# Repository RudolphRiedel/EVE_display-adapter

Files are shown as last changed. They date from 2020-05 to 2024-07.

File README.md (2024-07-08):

# EVE_display-adapter for 3D printers

These adapter boards connect a couple of FTDI/Bridgetek based FT81x/BT81x display modules with 3D-printer controller boards.
Basic support is present already in Marlin Bugfix 2.0x: ExtUI
Recommended are 4.3" displays with 480x272 or 5.0" displays with 800x480.

The form factor with the two mounting holes allows replacing a RepRap gfx-display.

L-D5019-01-0x: to be used with displays from Matrix Orbital or Riverdi.

L-D5019-05-0x: to be used with displays from Crystalfontz.

The design source files are for Altium Designer.

But everything else to order boards and build them without AD is included as well.

The design of the "EXP1" header is optimised for the Fysetc Cheetah as I do have two of these and can therefore
test my changes in Marlin with my displays.

Also, the Cheetah is one of the very few 3D-printer controller boards that allows to use hardware-SPI with the display.

The adapter boards can also be configured to be used with at least the original CR-10/Ender-3 boards using software-SPI.

Recommended displays for now with L-D5019-01-0x:
- EVE3-43G https://www.matrixorbital.com/eve3-43g
- EVE3-50G https://www.matrixorbital.com/eve3-50g
- RVT43ULBNWC00 (RiTFT-43-CAP-UX) https://riverdi.com/product/ritft43capux/

Recommended displays for now with L-D5019-05-0x:
- CFAF800480E0-050SC https://www.crystalfontz.com/product/cfaf800480e1050sca11-800x480-eve-accelerated-tft

Before connecting any display to your controller board, make sure the board can take the additional load on the 5V!

And you need to use a flat-flex-cable with connections on opposite sides.

The D5019-01-04 and D5019-05-02 boards do work both, I was not satisfied with the loudness of the speaker though.

I ran a series of performance tests with two microcontroller boards and the same 5cm cable from these boards to the display-adapter boards.

One of the microcontroller boards was this: https://github.com/RudolphRiedel/SAMC21_one
The "SAMC21 One" has an ATSAMC21E18A running at 48MHz and 5.0V.

The other one has an ATSAME51J19A running at 120MHz and 3.3V.

The D5019-01-04 was tested with an EVE3-50G featuring a BT815 running at 72MHz.

The D5019-05-02 was tested with a CFAF800480E0-050SC featuring a FT813 running at 60MHz.

Both boards performed similar enough to present the numbers together.

ATSAMC21
- 12MHz max for reliable touch events
- 35MHz max for still displaying a stable image

ATSAME51
- 17MHz max for reliable touch events
- 40MHz max for still displaying a stable image

Note, I reduced the main clock to find the maximum read spead and overclocked the controllers for the maximum write speed.
Also the maximum write speed is out of spec for both the FT813 and the BT815.

As the target speed for these boards with Marlin is 8MHz on hardware-SPI and <2MHz on software-spi,
I conclude that the performance of the SPI on these boards is well within the desired limits.

D5019-01-05 with the 3.3V LDO works fine with a EVE3-43G that has been modified to dual supply.

D5019-05-03 is ordered, it has the same 3.3V LDO and speaker as the D5019-01-05.

# EVE_display-adapter for use with breadboards

L-D5019-08-0x: simplified PCB to be used with displays from Matrix Orbital or Riverdi.

The schematic is pretty much the same as L-D5019-01 with a few modifications.
- all the series resistors are set to 56R
- the SPI line filter capacitors are set to not populated
- the "amplifier" circuit and the speaker is gone
- the 2x5 header for 3D printers is replaced with a 1x7 header
- an additional 1x8 header allows to connect a logic-analyzer plus an extra GND pin for split-supply setups
- the layout and the pinout of the 1x7 header is optimized for the pinout of the 20 pin ffc
- there is a little more space around the parts to allow for easier soldering
- pinout printed in copper on the pcb with no solder mask, no more need to check the documentation when connecting the board with jumper wires

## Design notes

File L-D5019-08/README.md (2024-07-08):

# EVE_display-adapter for use with evaluation boards

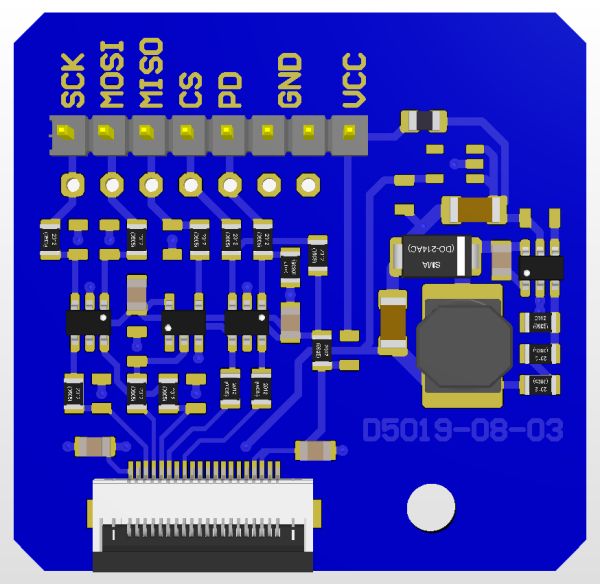
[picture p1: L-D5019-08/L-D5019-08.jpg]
L-D5019-08


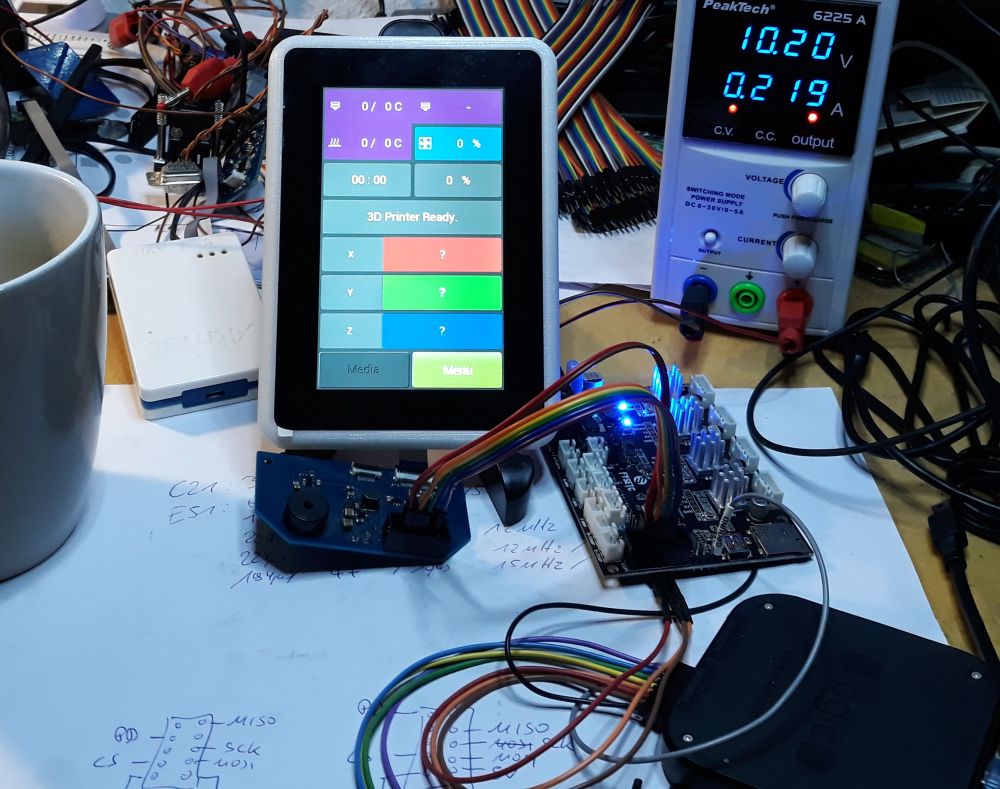
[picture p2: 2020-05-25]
Images/Marlin_Cheetah_EVE3-50G.jpg

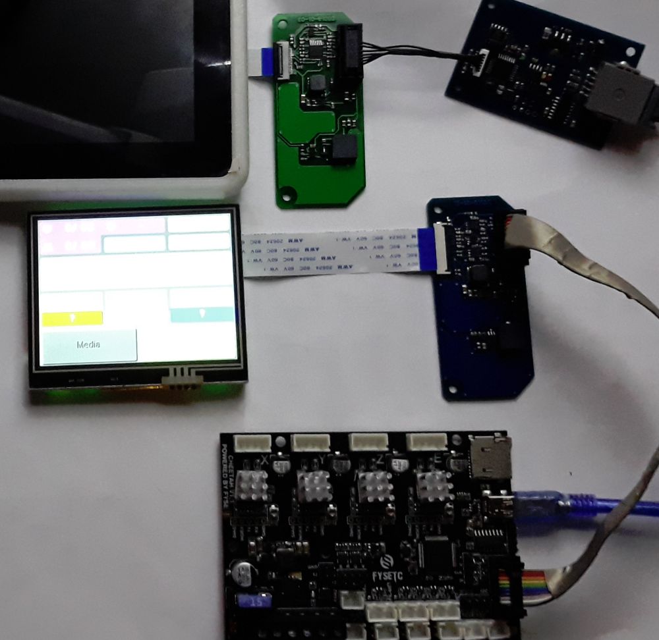
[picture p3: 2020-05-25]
Images/Marlin_Cheetah_Crystalfontz.jpg

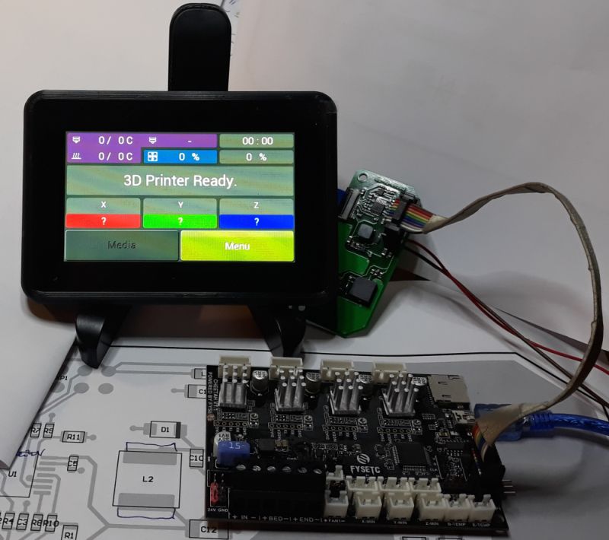
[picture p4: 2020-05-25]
Images/Marlin_Cheetah_EVE3-43G.jpg

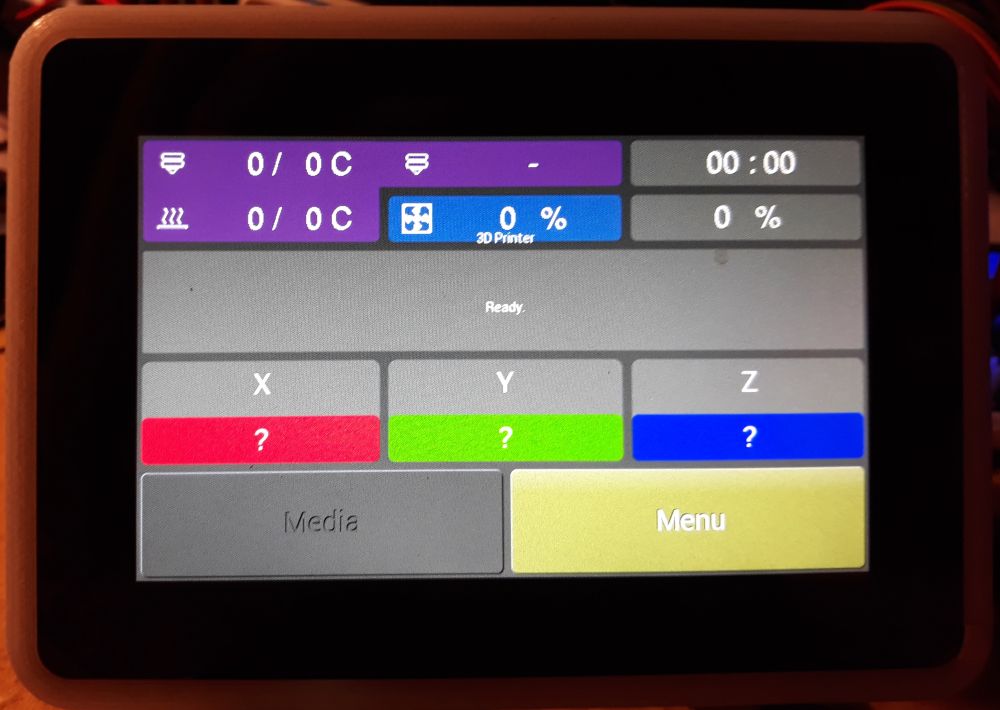
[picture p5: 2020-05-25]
Images/Marlin_EVE3-50G.jpg

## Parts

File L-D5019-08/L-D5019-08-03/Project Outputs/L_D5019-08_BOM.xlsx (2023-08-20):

Comment | Designator | Footprint | JLCPCB Part #
100n | C100, C106, C110 | 0805 | C49678
4µ7 | C101, C107 | 0805 | C1779
4µ7 | C111 | 1206 | C29823
22µF | C112 | 1206 | C12891
MBRA340T3G‎ | D100 | SMA | C8678
0R0 | L100, R102 | 0805 | C17477
xNR6028T4R7M | L101 | 6x6 mm | do not populate
56R | R100, R101, R103, R104, R107, R108, R109, R110, R112, R113 | 0805 | C17757
10k | R106, R111, R116, R117 | 0805 | C17414
22k | R115 | 0805 | C17560
x74LVC2G17 | U100, U101 | SOT23-6 | C3294723
x74VHC1GT125 | U102 | SOT23-5 | C457671
RT8259GE | U103 | SOT23-6 | C16819
x1x8 2,54mm | X100 |  | do not populate
687120149022 | X101 | FPC 0.5mm | C262274

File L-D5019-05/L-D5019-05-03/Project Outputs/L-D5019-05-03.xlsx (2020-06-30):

Quantity | Designator | Value | PackageDescription | Description | Manufacturer | Part Number | Distributor_1 | Distributor_1_Part_Number
4 | C1, C6, C9, C11 | 100n | 0805 | 0805 Chip Capacitor |  | CAPC_0805
4 | C2, C3, C4, C5 | 22p | 0805 | 0805 Chip Capacitor |  | CAPC_0805
4 | C7, C14, C16, C18 | 4µ7 | 0805 | 0805 Chip Capacitor |  | CAPC_0805
1 | D3 | TS4148 RY | 0805 | Small Signal Diode IF 0.3A, VR 75V, 0805 | TSC | TSC_TS4148 RY
1 | EXP1 | 2x5 2,54mm |  | Pin-Header 2,54 mm 2x5pins, shrouded |  | PINH_2x5_2_54
1 | H1 | CT-1205H-SMT | SMT, 13x13 | Speaker, Magnetic, 47R, 60mA, 88dBA, SMT, 12.8 x 12.8 mm, height 10 mm | CUI | CT-1205H-SMT | Digi-Key | 102-1266-1-ND
1 | L1 | 0R0 | 0805 | 0805 Chip Inductor |  | INDC_0805
4 | R2, R15, R18, R24 | 0R0 | 0805 | 0805 Chip Resistor |  | RESC_0805
10 | R3, R4, R5, R6, R8, R9, R10, R11, R14, R16 | 10R | 0805 | 0805 Chip Resistor |  | RESC_0805
2 | R7, R12 | 10k | 0805 | 0805 Chip Resistor |  | RESC_0805
1 | R19 | 1k | 0805 | 0805 Chip Resistor |  | RESC_0805
2 | U1, U2 | 74LVC2G17 | SOT23-6 | Dual Schmitt-Trigger Buffer with 5.5V tolerant inputs | TI | 74LVC2G17 | Digi-Key | 296-SN74LVC2G17DBVRCT-ND‎
2 | U3, U4 | 74VHC1GT125 | SOT23-5 | 1x Buffer with OE; 3-state,Level Shifter 3,3V to 5V and 5V to 3.3V | ON Semiconductor | 74VHC1GT125 | Farnell | 1703291
1 | U6 | MIC5504-3.3YM5 | SOT23-5 | 300 mA LDO, Vin=2,5V…5,5V, Vout= 3,3V, -40°C..125°C | Microchip | MIC5504-3.3YM5 | Farnell | 2510377
1 | V1 | BC817 | SOT23 | NPN Transistor SOT23, 1=B, 2=C, 3=E |  | BC817
1 | X1 | WE_687130149022 | FPC 0.5mm | 30pin WR-FPC 0.50 mm SMT ZIF Horizontal - Bottom Contact | Wuerth | WE_687130149022 | Digi-Key | 732-6007-1-ND

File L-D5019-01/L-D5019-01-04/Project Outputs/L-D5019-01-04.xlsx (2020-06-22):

Quantity | Designator | Value | PackageDescription | Description | Manufacturer | Part Number | Distributor_1 | Distributor_1_Part_Number
5 | C1, C6, C9, C11, C13 | 100n | 0805 | 0805 Chip Capacitor |  | CAPC_0805
4 | C2, C3, C4, C5 | 22p | 0805 | 0805 Chip Capacitor |  | CAPC_0805
2 | C7, C14 | 4µ7 | 0805 | 0805 Chip Capacitor |  | CAPC_0805
1 | C15 | 22µF | 1206 | 1206 Chip Capacitor |  | CAPC_1206
1 | D1 | TS4148 RY | 0805 | Small Signal Diode IF 0.3A, VR 75V, 0805 | TSC | TSC_TS4148 RY
1 | D2 | ES07D | DO-219AB | Ultrafast Rectifier Surface Mount, IF 0.5A, VR 100V, DO-219AB, AEC-Q101 | Vishay | ES07D
1 | EXP1 | 2x5 2,54mm |  | Pin-Header 2,54 mm 2x5pins, shrouded |  | PINH_2x5_2_54
1 | H1 | PKM17EPP-2002-B0 | THT, 17mm dia | Speaker, Piezo, THT, dia 17mm, height 8.6 mm | Murata | PKM17EPP-2002-B0 | Digi-Key | 490-4688-ND
1 | L1 | 0R0 | 0805 | 0805 Chip Inductor |  | INDC_0805
1 | L2 | VLS6045AF-4R7M | 6x6 mm | 4,7µH, shielded, 4,7A, 26mR | TDK | VLS6045AF-4R7M | Digi-Key | 445-180835-1-ND
3 | R2, R15, R18 | 0R0 | 0805 | 0805 Chip Resistor |  | RESC_0805
10 | R3, R4, R5, R6, R8, R9, R10, R11, R14, R16 | 10R | 0805 | 0805 Chip Resistor |  | RESC_0805
5 | R7, R12, R20, R22, R23 | 10k | 0805 | 0805 Chip Resistor |  | RESC_0805
2 | R17, R19 | 1k | 0805 | 0805 Chip Resistor |  | RESC_0805
1 | R21 | 22k | 0805 | 0805 Chip Resistor |  | RESC_0805
2 | U1, U2 | 74LVC2G17 | SOT23-6 | Dual Schmitt-Trigger Buffer with 5.5V tolerant inputs | TI | 74LVC2G17 | Digi-Key | 296-SN74LVC2G17DBVRCT-ND‎
2 | U3, U4 | 74VHC1GT125 | SOT23-5 | 1x Buffer with OE; 3-state,Level Shifter 3,3V to 5V and 5V to 3.3V | ON Semiconductor | 74VHC1GT125 | Farnell | 1703291
1 | U5 | RT8259GE | SOT23-6 | Step-Down DC/DC Regulator, 24V, 1.2A, 1,4MHz | Richtek | RT8259GE | Digi-Key | 1028-1497-1-ND
1 | V1 | BC817 | SOT23 | NPN Transistor SOT23, 1=B, 2=C, 3=E |  | BC817
1 | X1 | WE_687120149022 | FPC 0.5mm | 20pin WR-FPC 0.50 mm SMT ZIF Horizontal - Bottom Contact | Wuerth | WE_687120149022 | Digi-Key | 732-6002-1-ND

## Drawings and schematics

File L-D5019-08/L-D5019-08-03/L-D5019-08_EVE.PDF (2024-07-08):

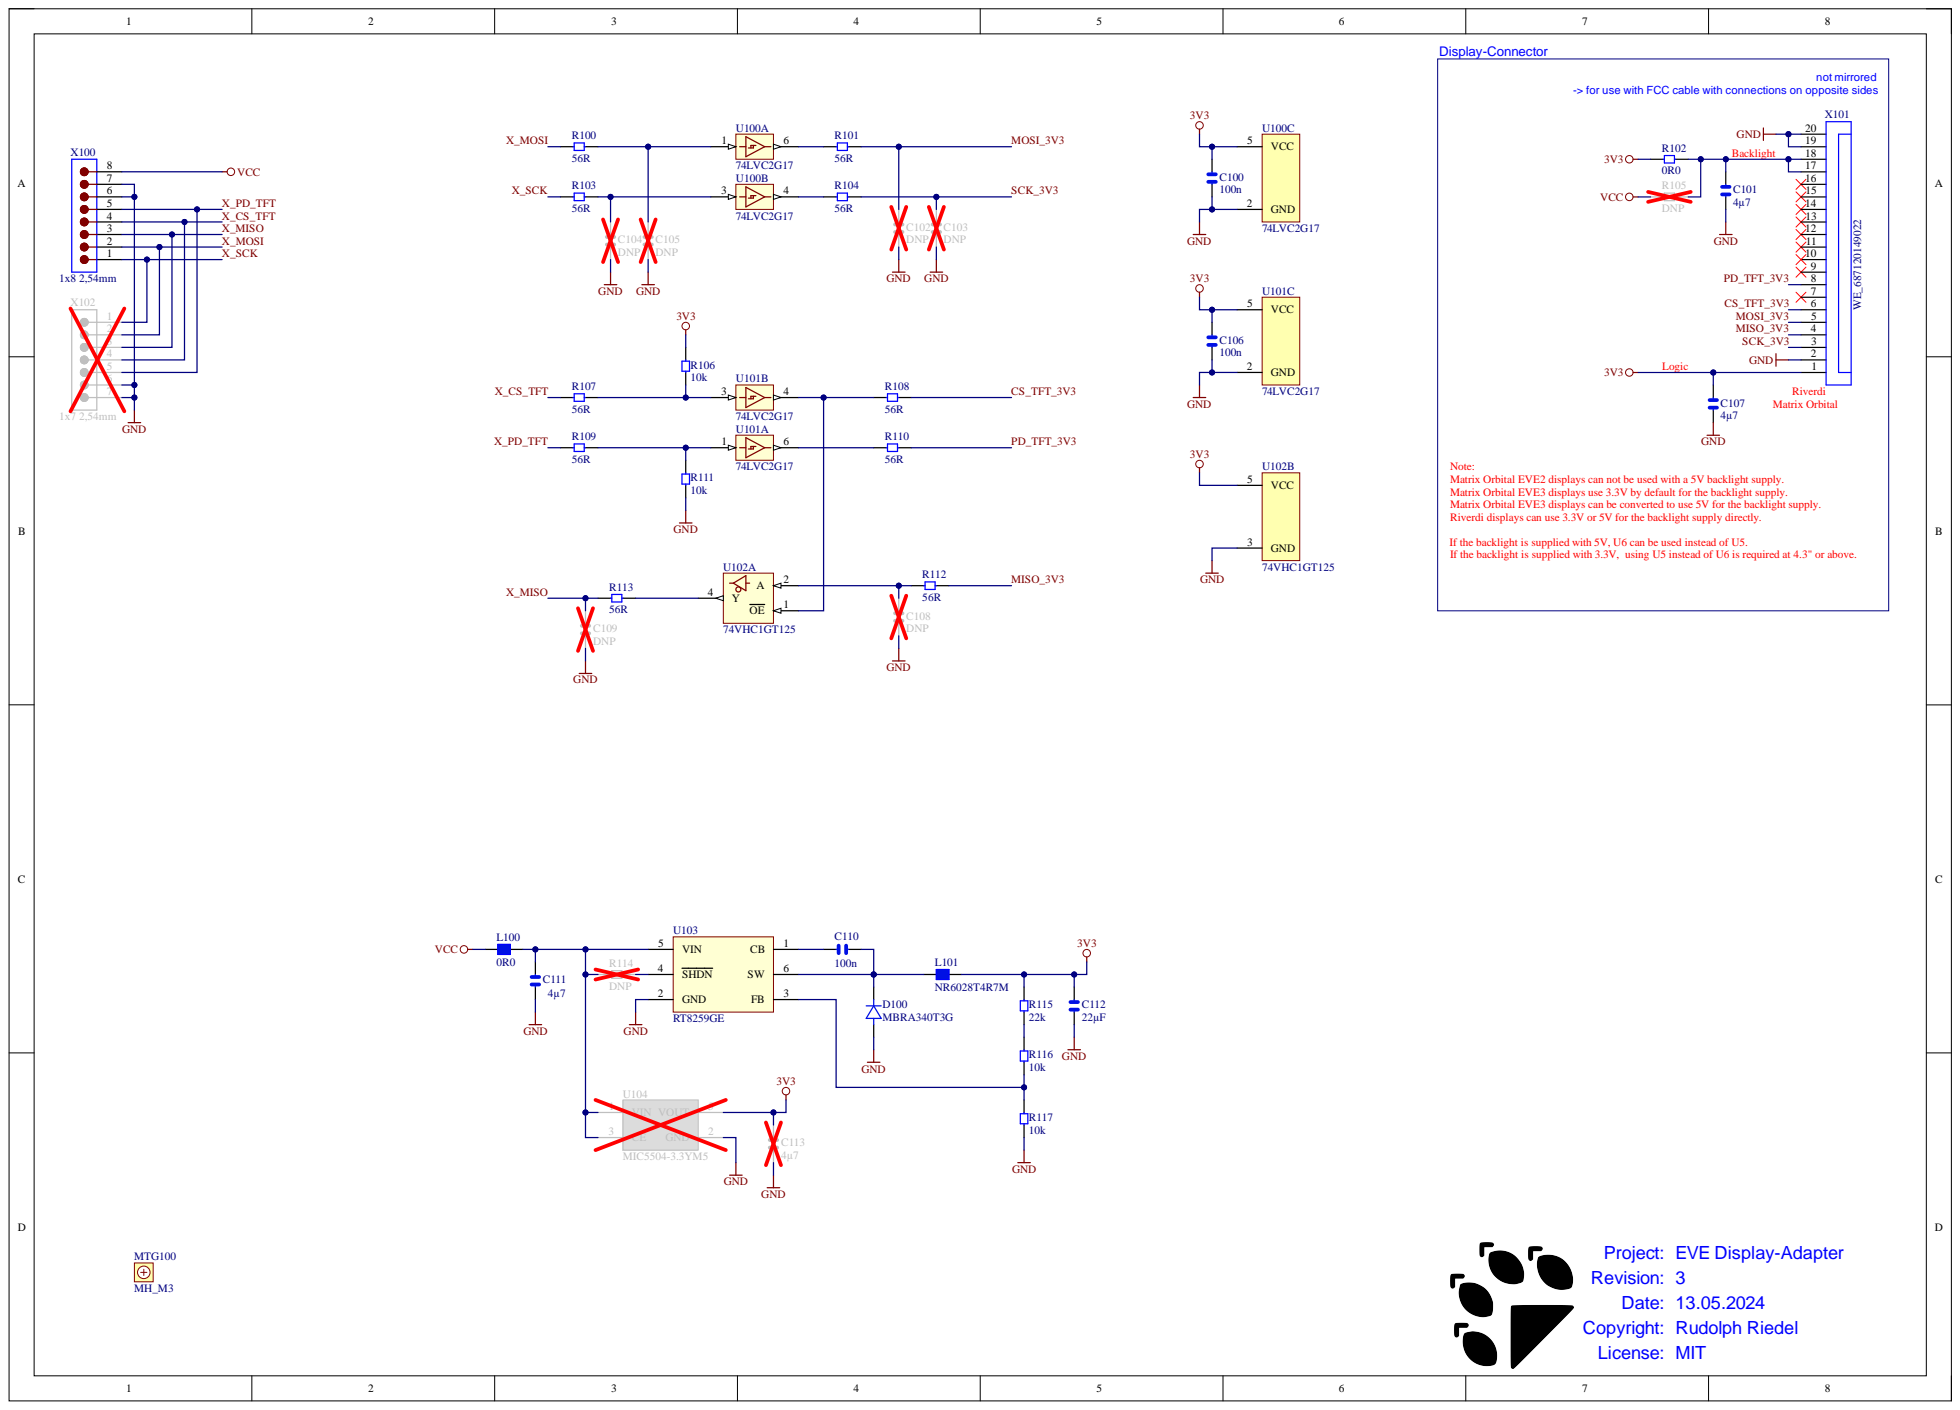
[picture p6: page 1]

use with FCC ca

Note
Matrix Orbital EVE2 displays c
Matrix Orbital EVE3 displays use 3.3V by de
Matrix Orbital EVE3 displays c
Rive

an not be used with a 5V ba

fault for the ba
rted to use 5V for the ba
cklight supply dir

an use 3.3V or 5V for the ba

cklight is supplied with 5V, U6 c
cklight is supplied with 3.3V, using U5 inste

an be used inste

ed at 4.3" or above

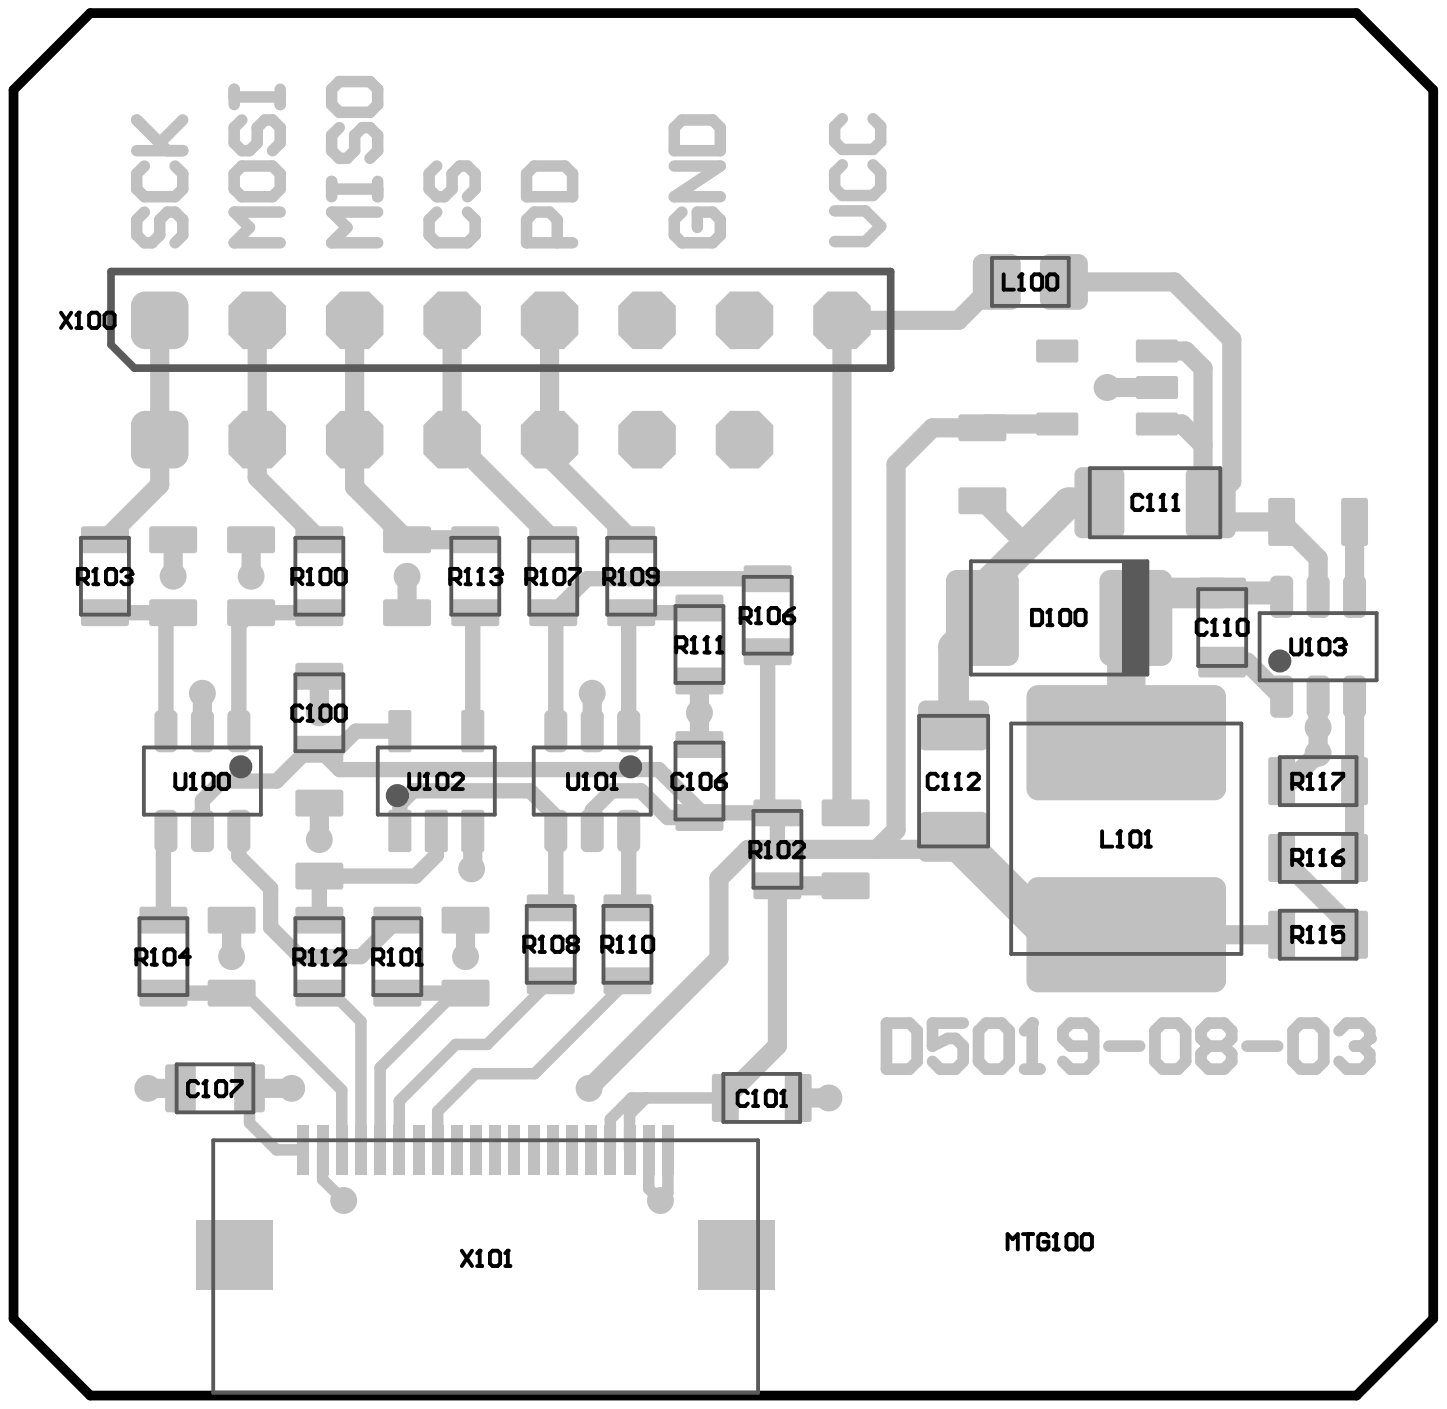
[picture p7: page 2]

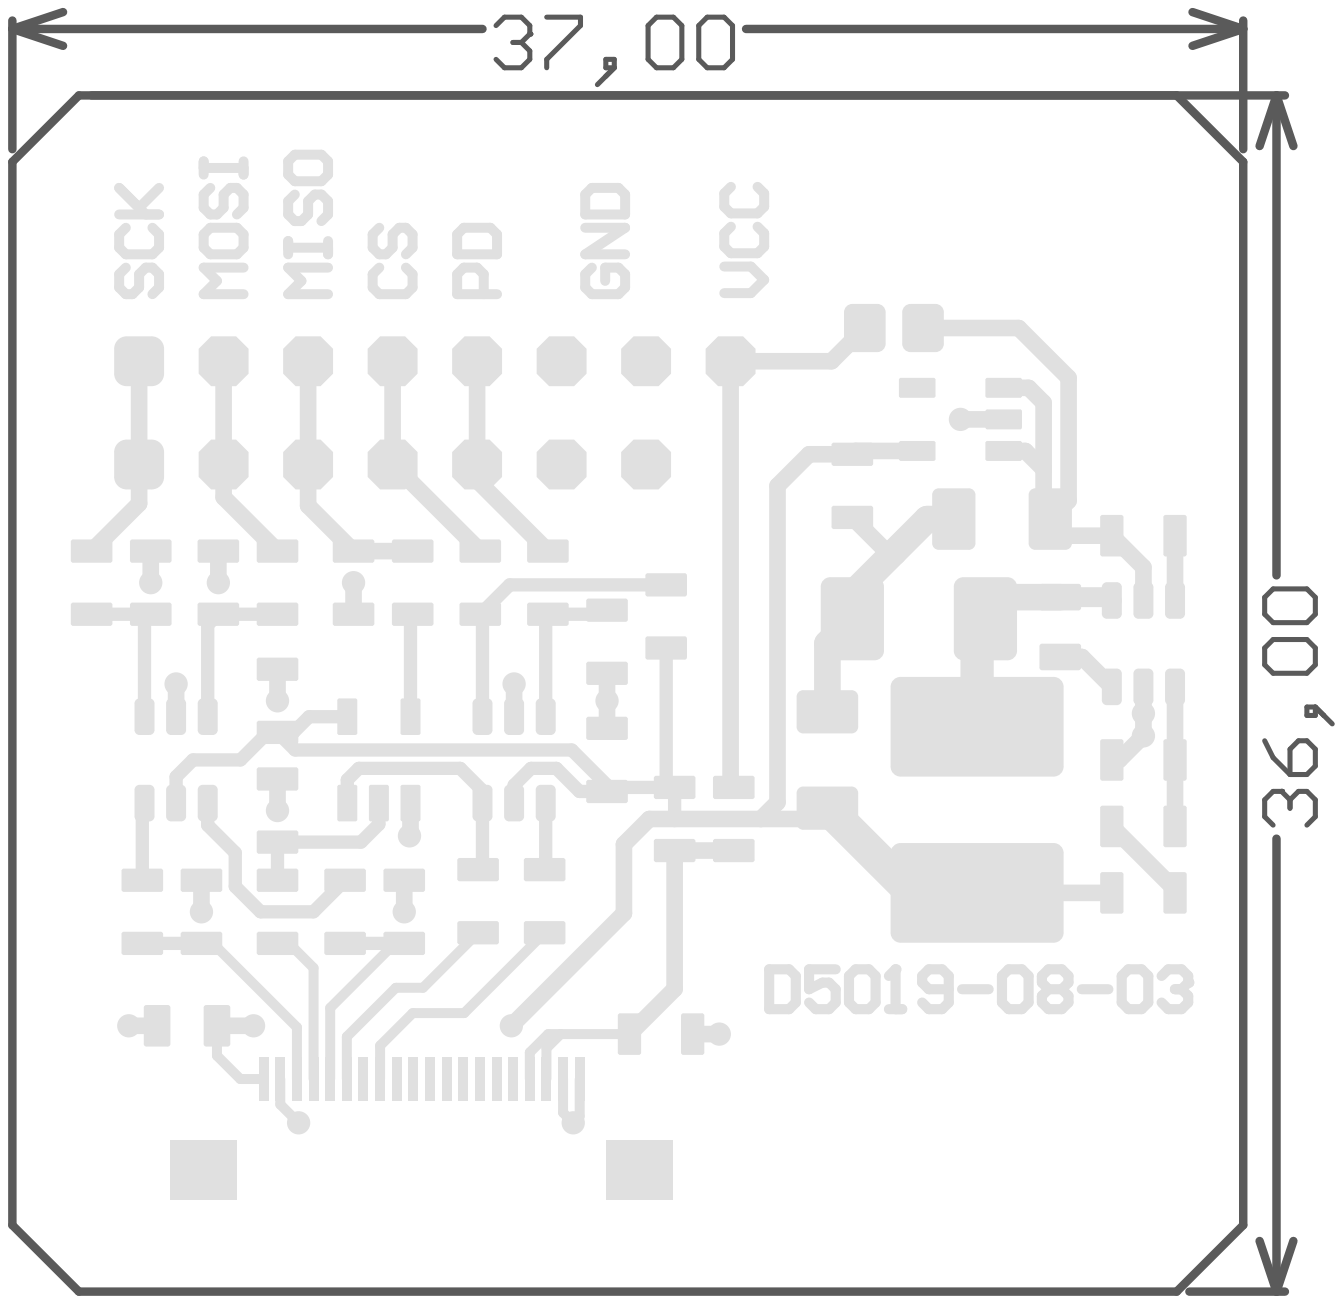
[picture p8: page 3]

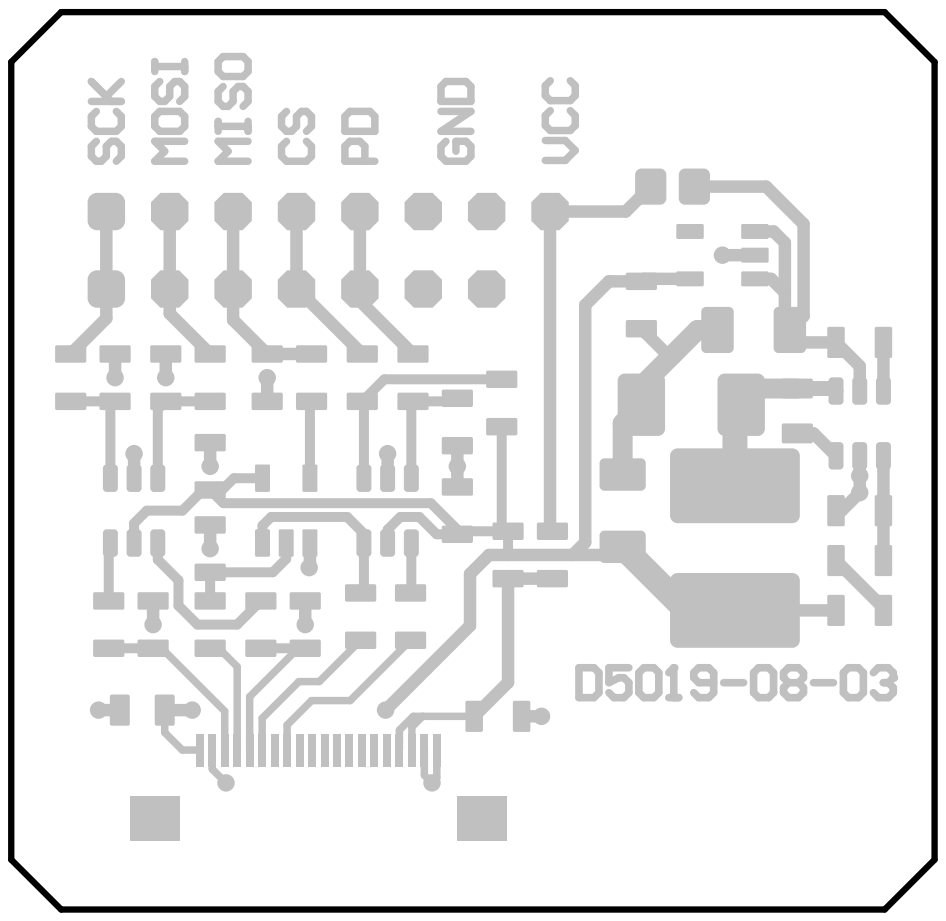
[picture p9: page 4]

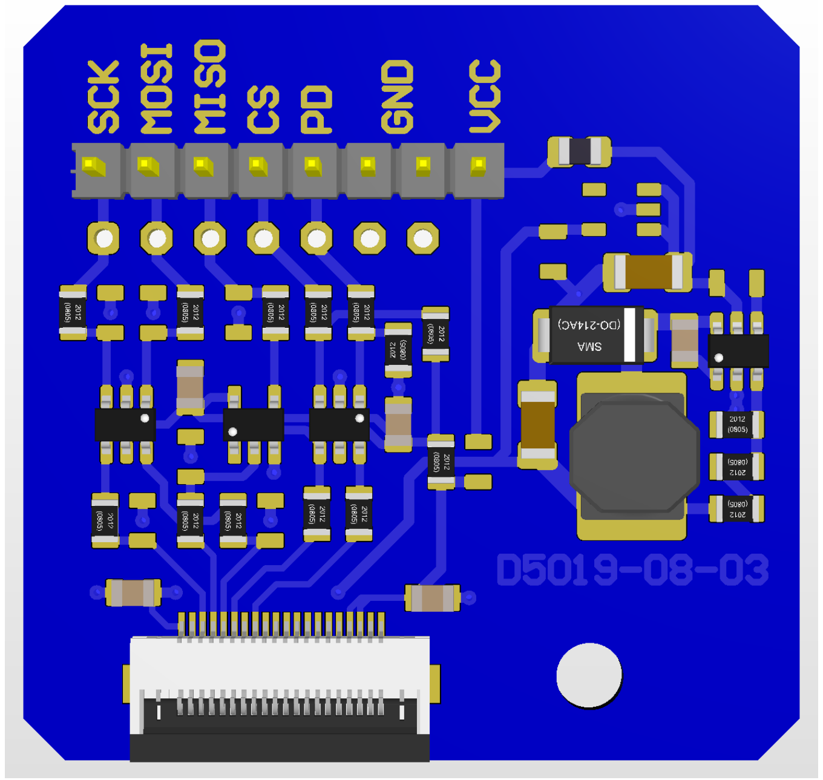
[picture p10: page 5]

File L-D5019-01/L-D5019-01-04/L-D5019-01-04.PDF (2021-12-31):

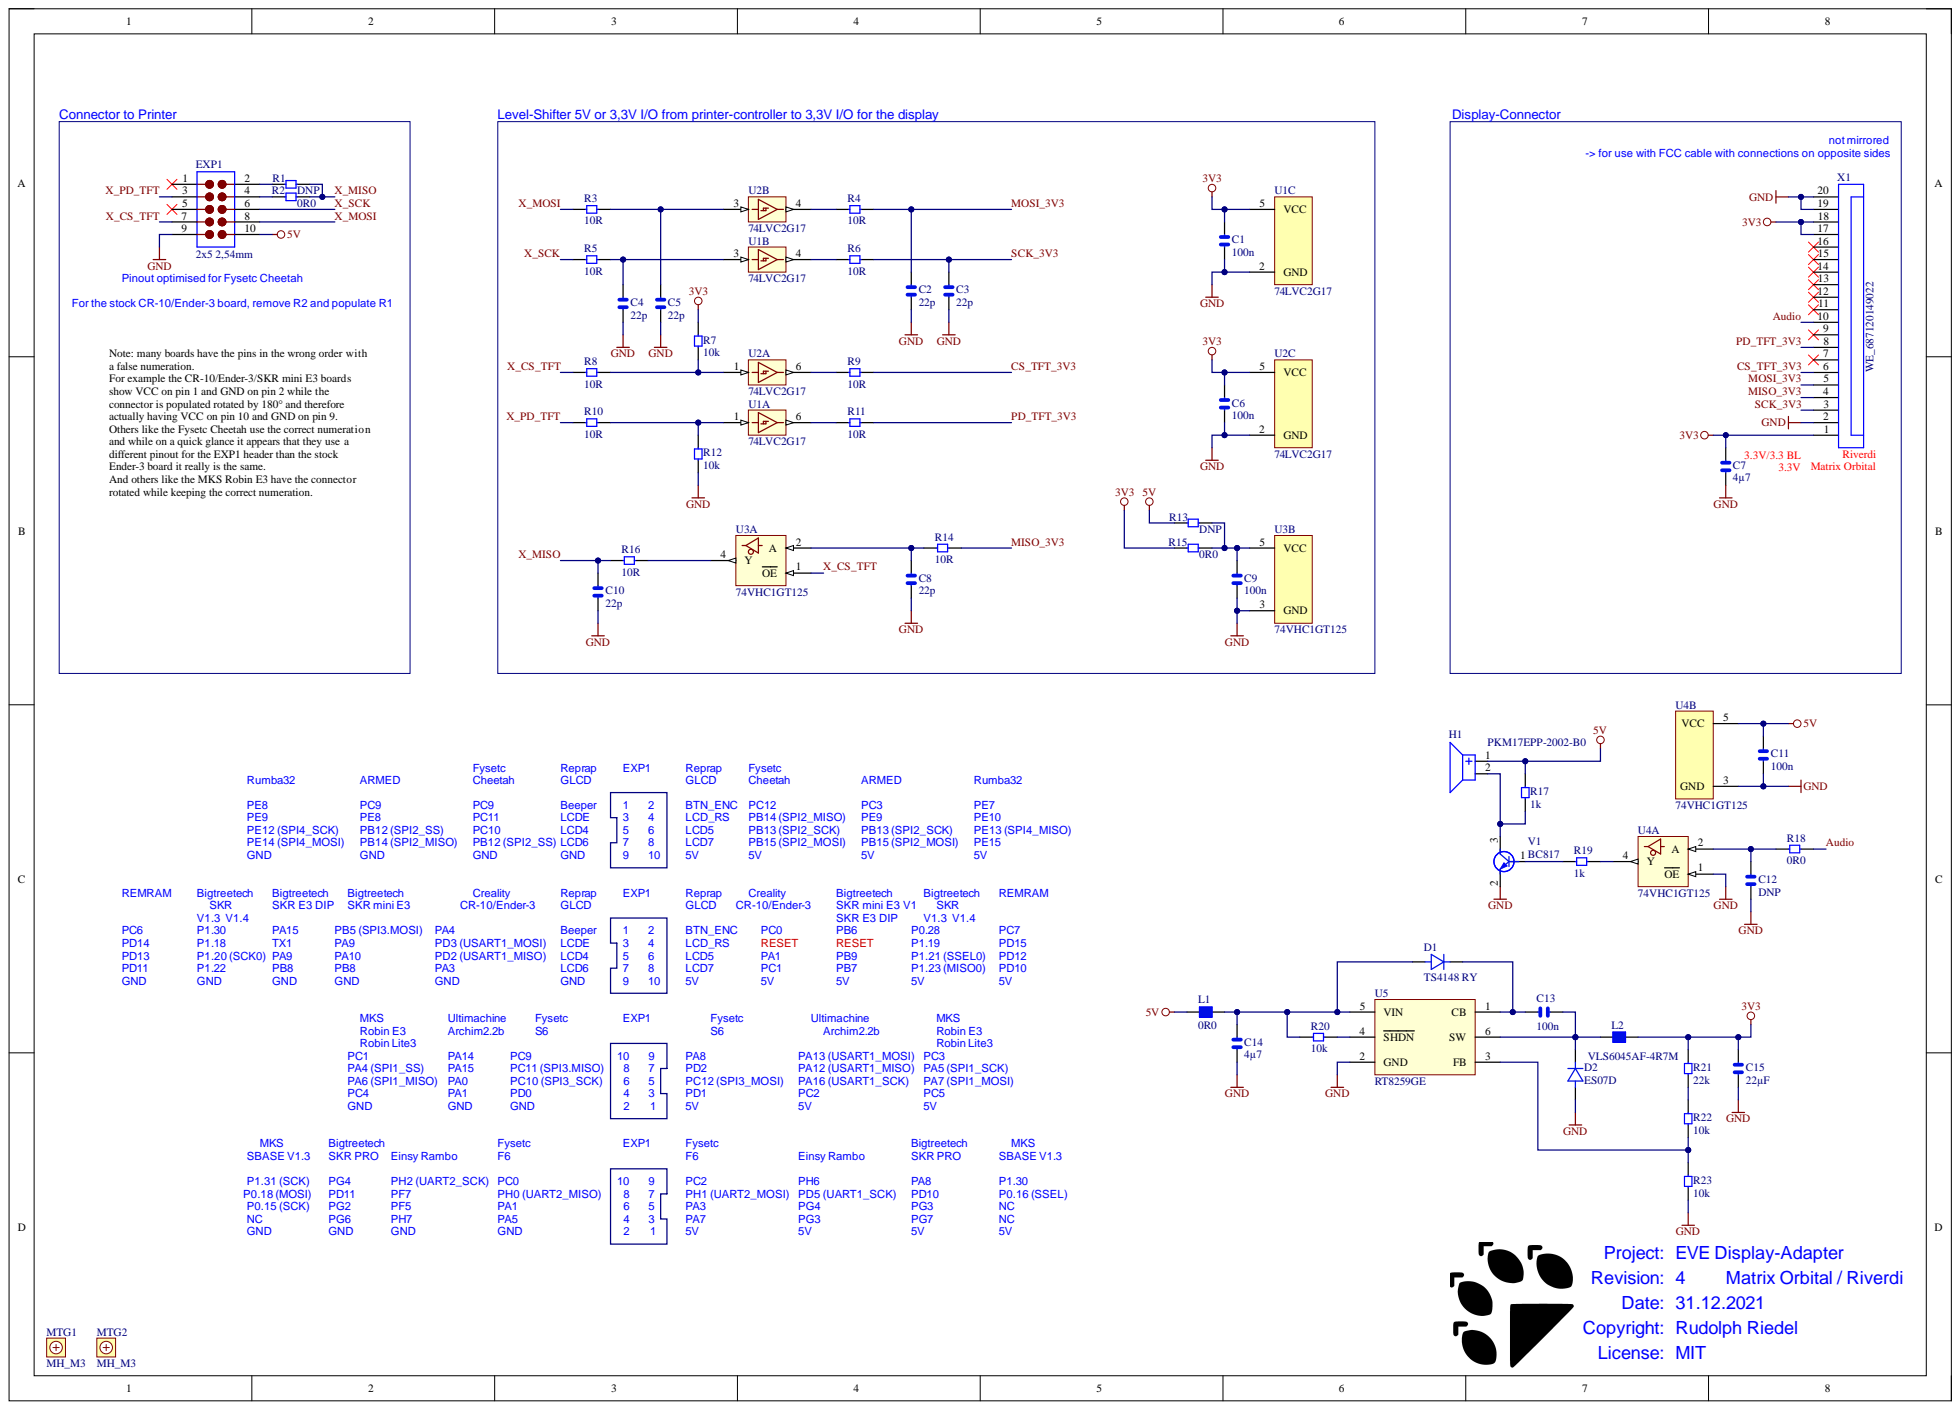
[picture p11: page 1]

Level-Shifter 5V or 3,3V I/O from printer-controller to 3,3V I/O for the display

-> for use with FCC cable with connections on opposite sides

GND
Pinout optimised for Fysetc Cheetah

For the stock CR-10/Ender-3 board, remove R2 and populate R1

Note: many boards have the pins in the wrong order with
a false numeration.
For example the CR-10/Ender-3/SKR mini E3 boards
show VCC on pin 1 and GND on pin 2 while the
connector is populated rotated by 180° and therefore
actually having VCC on pin 10 and GND on pin 9.
Others like the Fysetc Cheetah use the correct numeration
and while on a quick glance it appears that they use a
different pinout for the EXP1 header than the stock
Ender-3 board it really is the same.
And others like the MKS Robin E3 have the connector
rotated while keeping the correct numeration.

SHDN 4

GND 2 | | VLS6045AF-4R7M

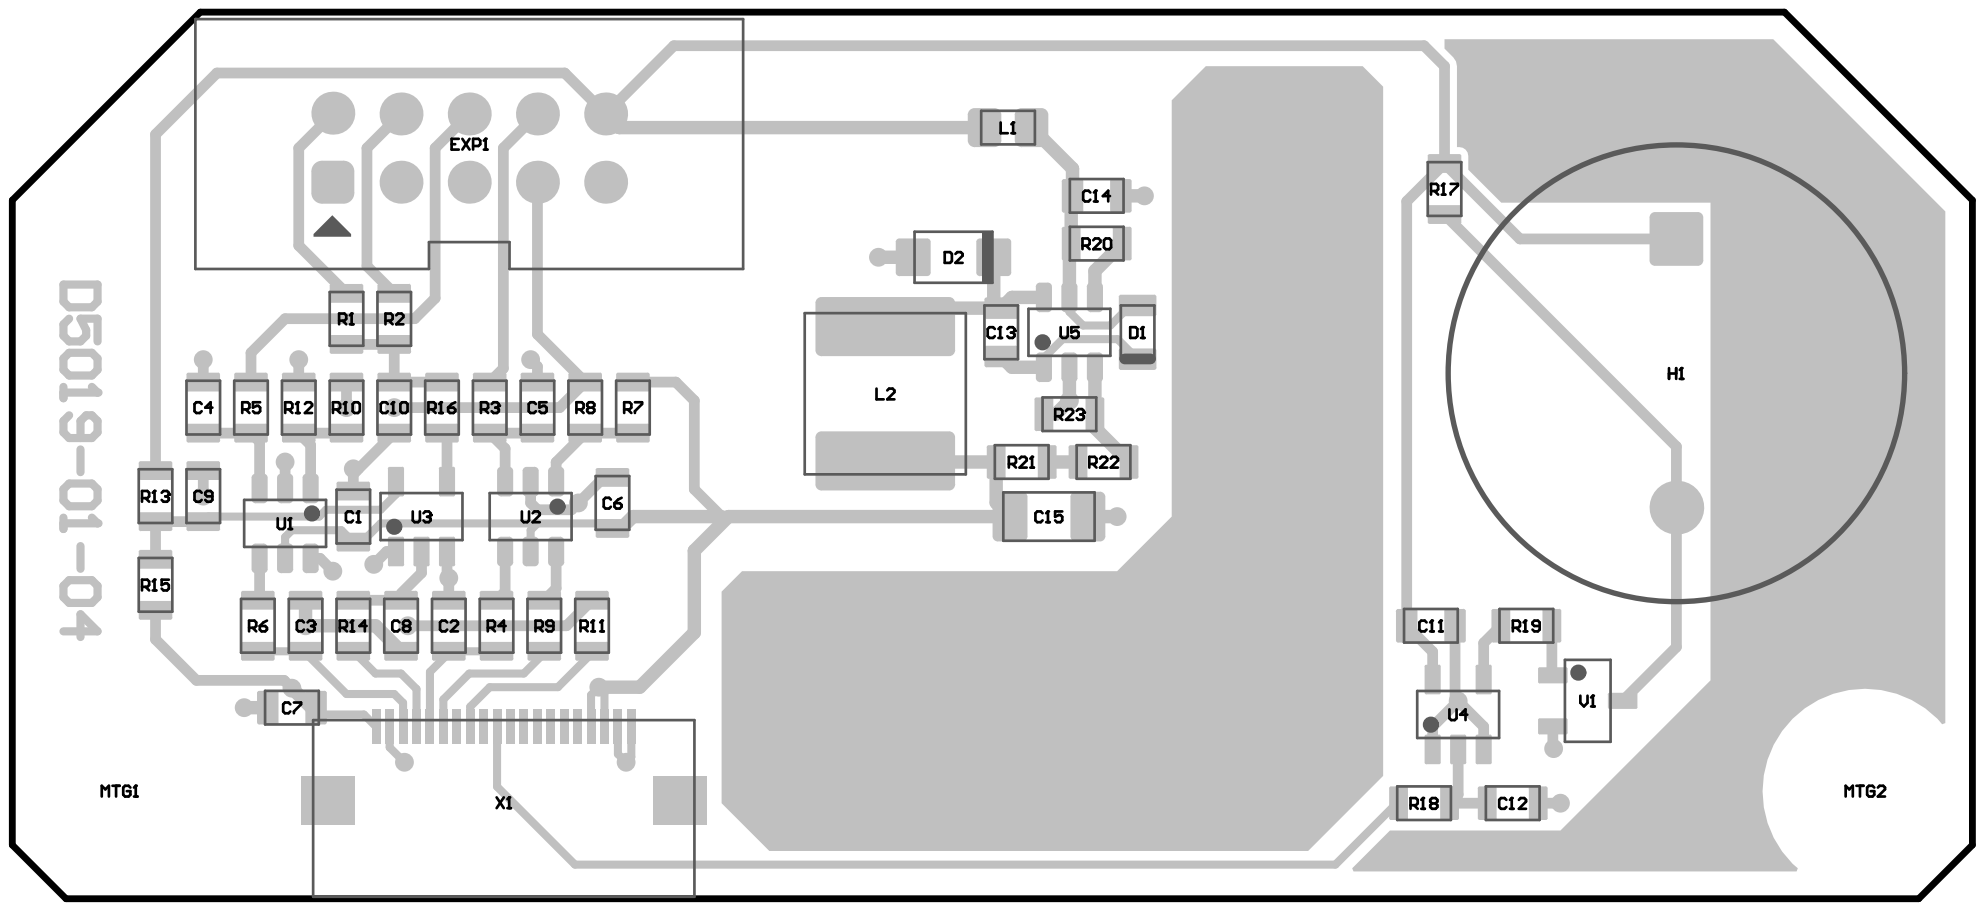
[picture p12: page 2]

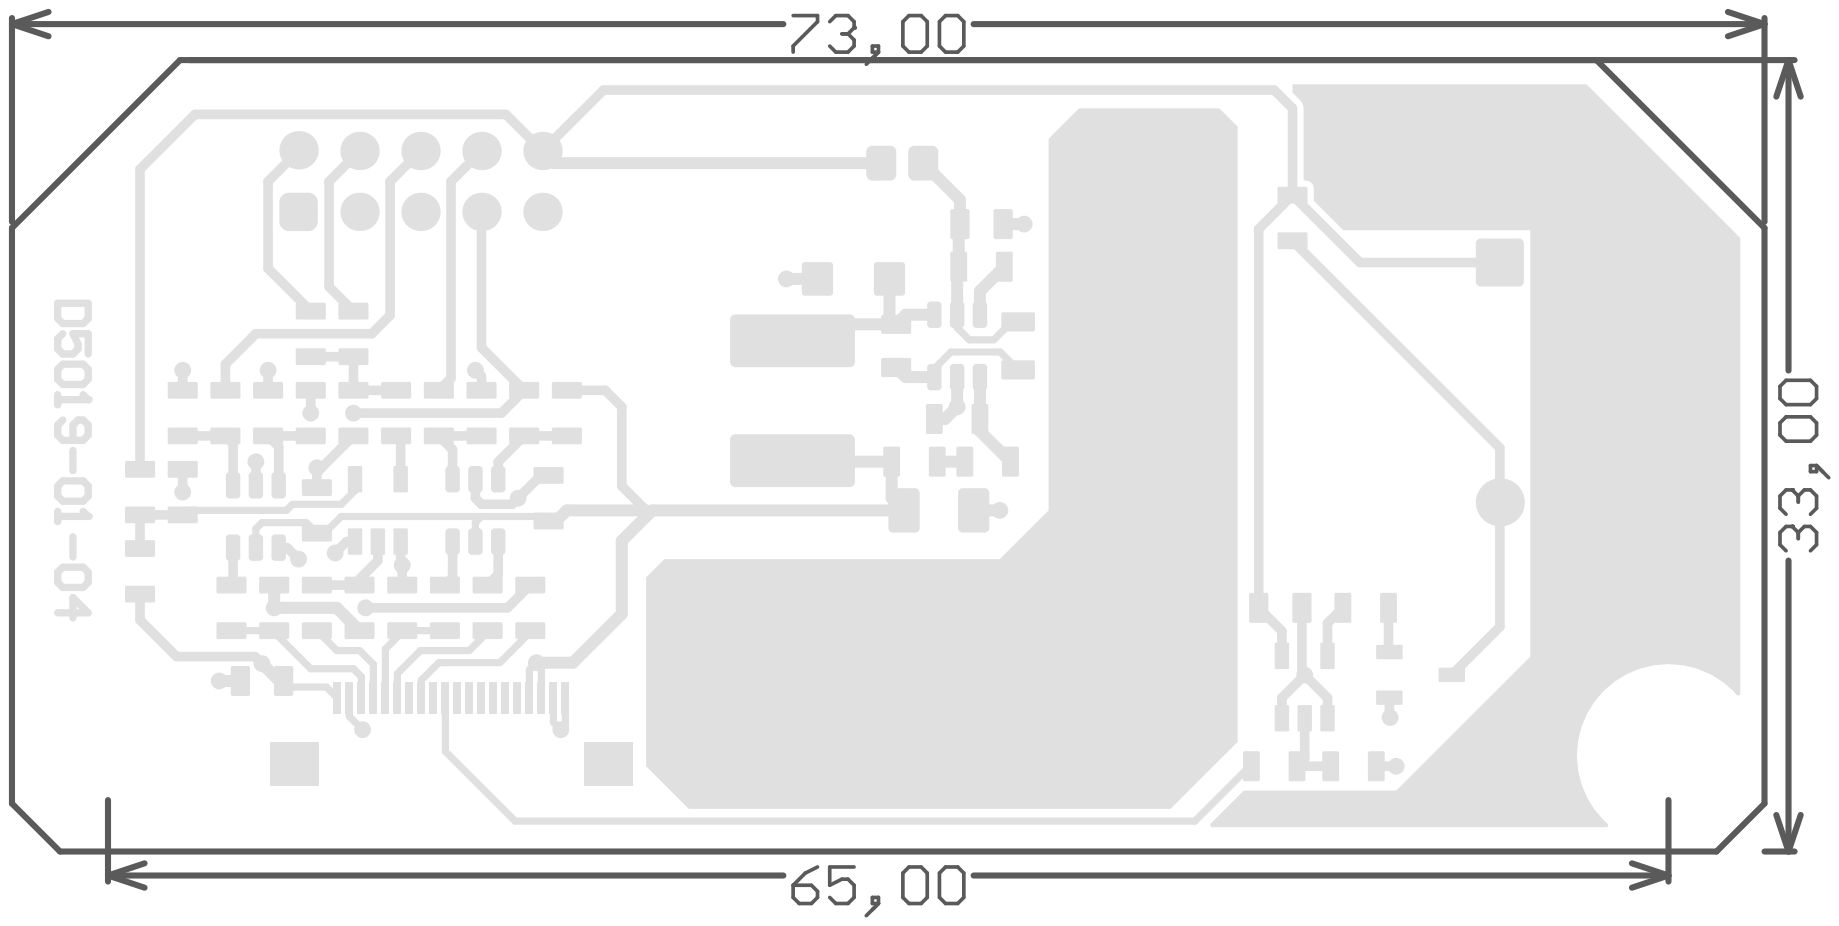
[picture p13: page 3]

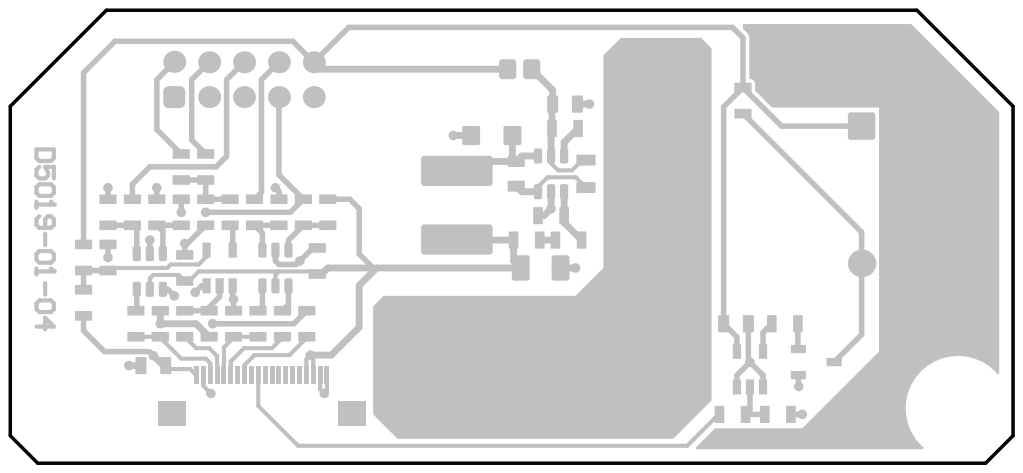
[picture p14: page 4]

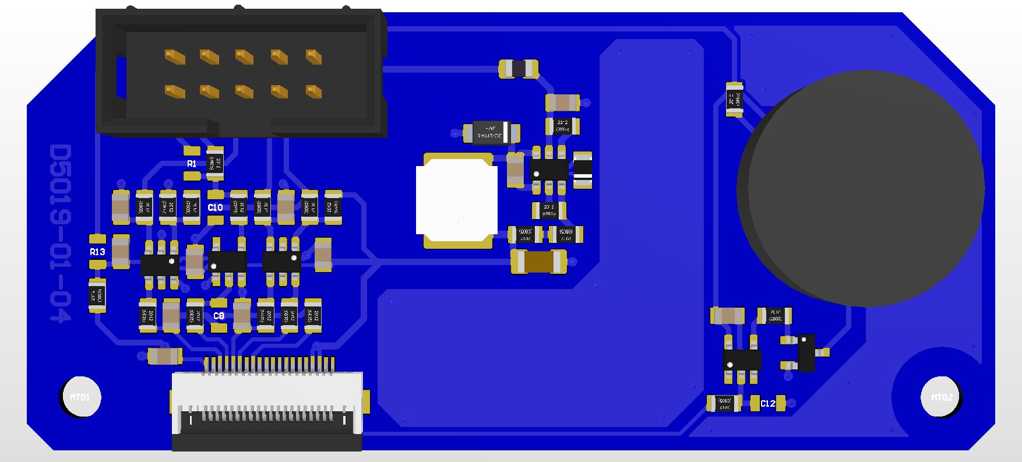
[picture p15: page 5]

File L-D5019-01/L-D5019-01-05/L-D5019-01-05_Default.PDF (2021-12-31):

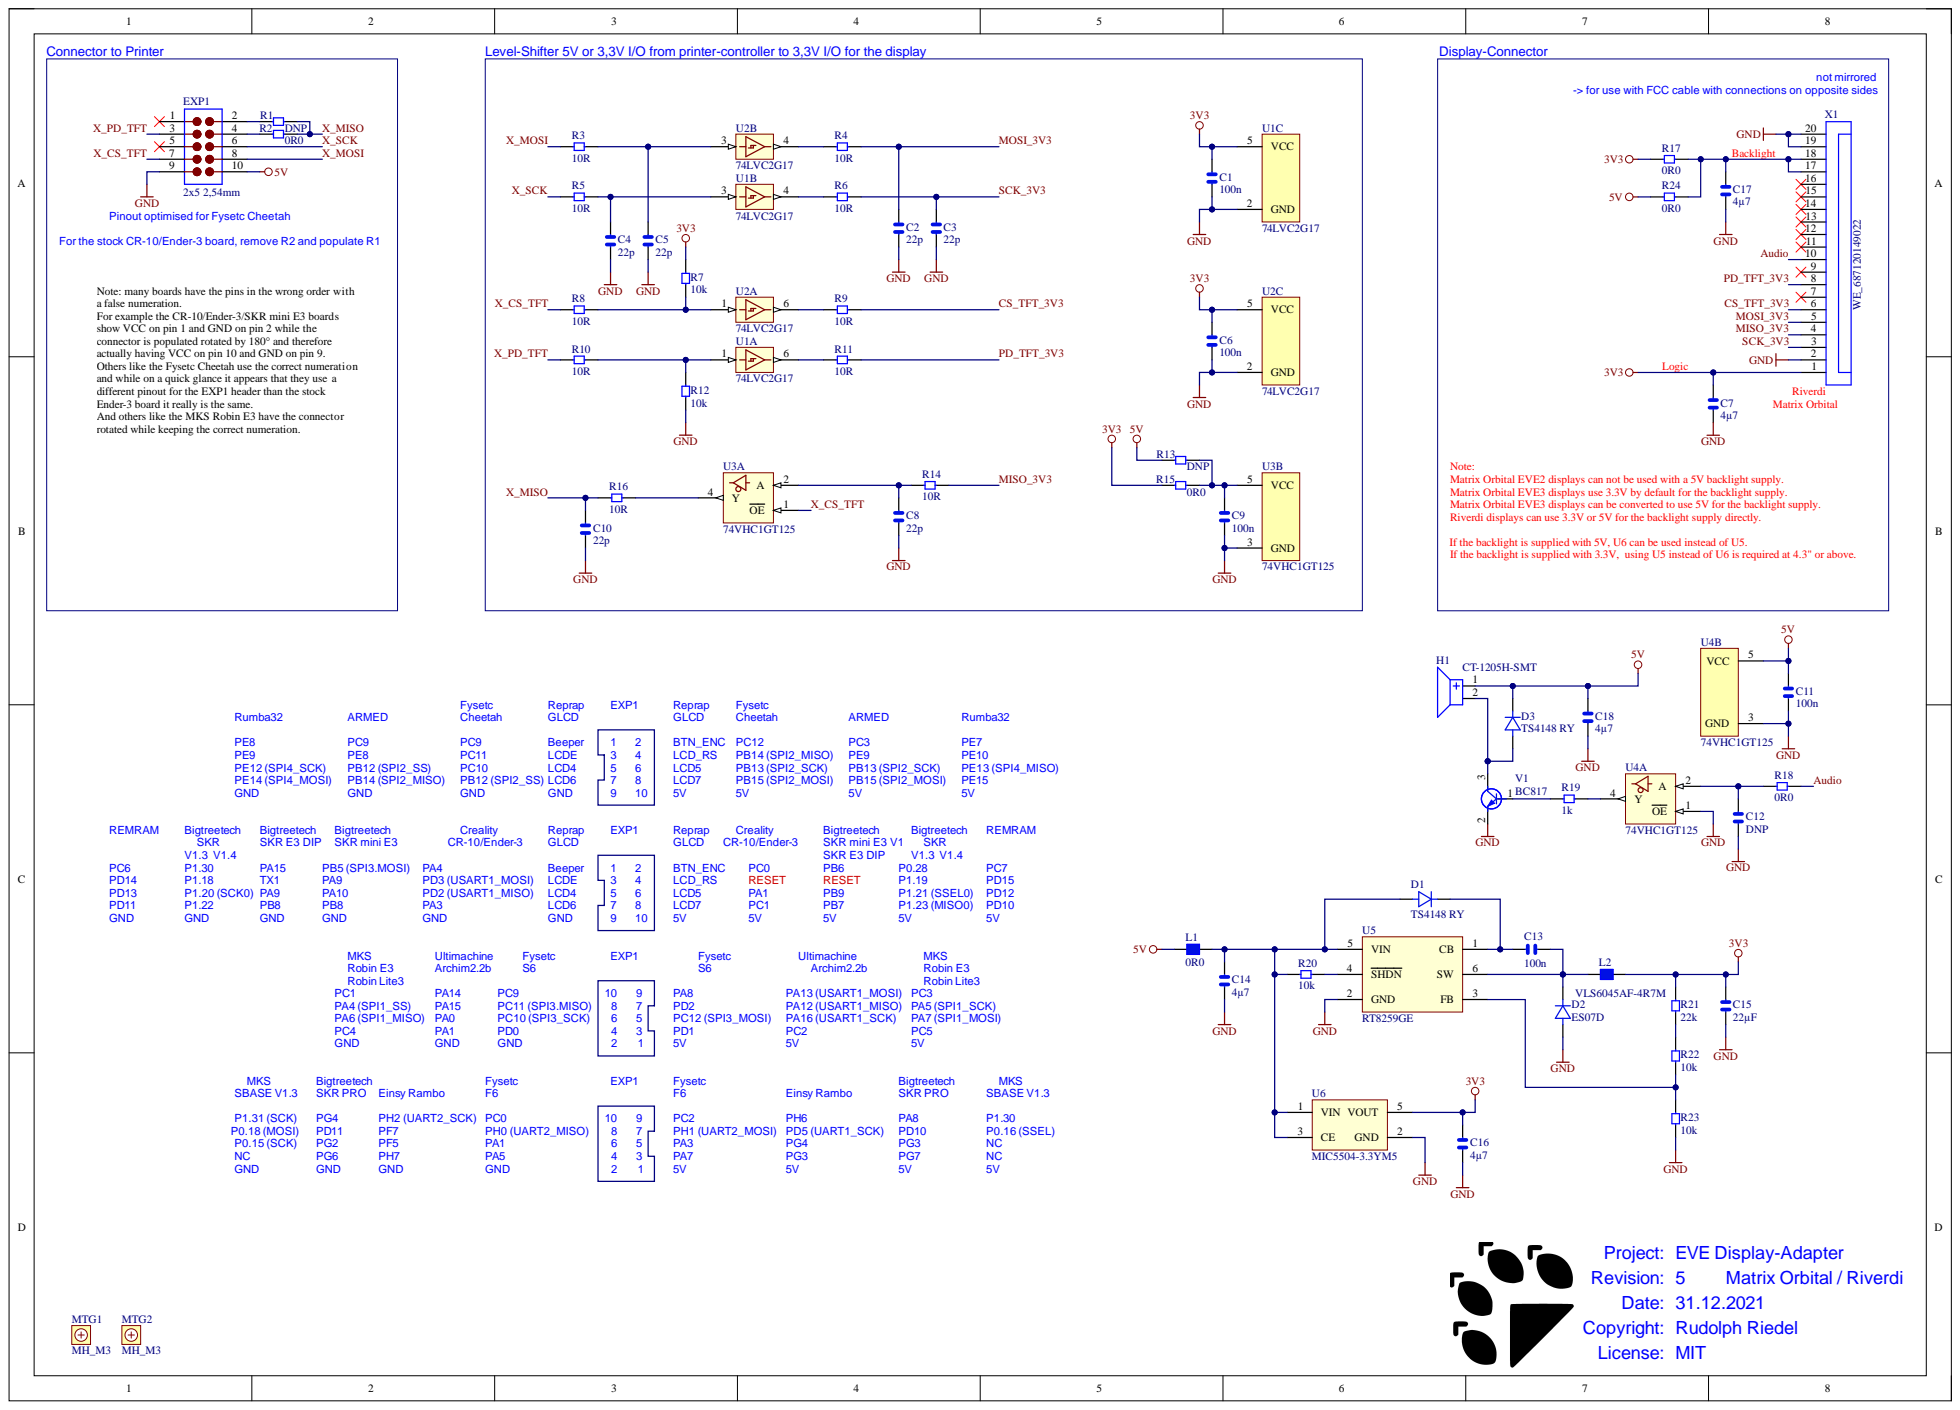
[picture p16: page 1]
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

-> for use with FCC cable with connections on opposite sides

GND
Pinout optimised for Fysetc Cheetah

For the stock CR-10/Ender-3 board, remove R2 and populate R1

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

Note:
Matrix Orbital EVE2 displays can not be used with a 5V backlight supply.
Matrix Orbital EVE3 displays use 3.3V by default for the backlight supply.
Matrix Orbital EVE3 displays can be converted to use 5V for the backlight supply.
Riverdi displays can use 3.3V or 5V for the backlight supply directly.

If the backlight is supplied with 5V, U6 can be used instead of U5.
If the backlight is supplied with 3.3V, using U5 instead of U6 is required at 4.3" or above.

SHDN 4

GND | ES07D

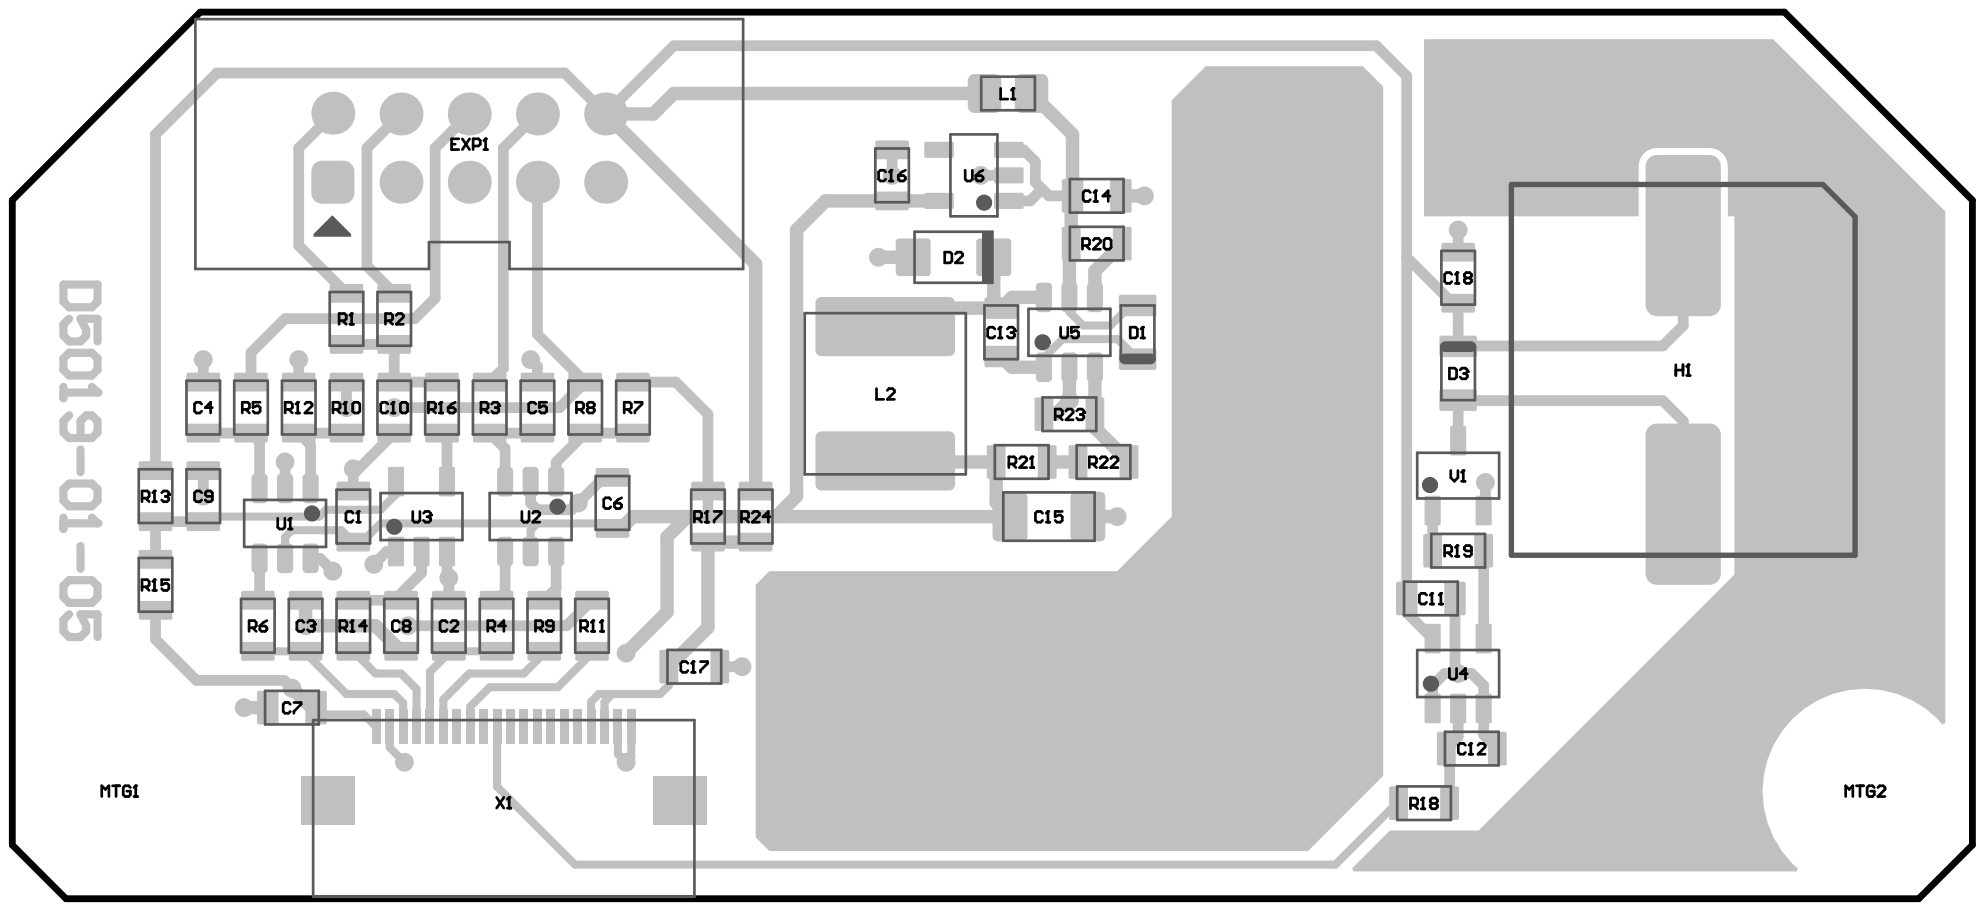
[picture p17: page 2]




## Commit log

2020-05-25 Initial commit.
    [L-D5019-01-04.PcbDoc, L-D5019-01-04.PrjPcb, L-D5019-01-04.SchDoc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]
2020-05-27 Update, new revisions will have a LDO for the 3.3V logic supply.
2020-06-10 New revision for the Matrix Orbital / Riverdi version: - new speaker that hopefully is a lot louder - optional 3.3V LDO - two variants, one for 3.3V only, one for 5V backlight-supply
    [L-D5019-01-05.PcbDoc, L-D5019-01-05.PrjPcb, L-D5019-01-05.SchDoc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]
2020-06-22 - removed C8 and C10 from all variants as tests showed that without these the SPI can be clocked a little faster
    [L-D5019-01-04.PrjPcb, L-D5019-01-04.SchDoc, L-D5019-01-04.xlsx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]
2020-06-30 - added D5019-05-03
    [L-D5019-05-03.PcbDoc, L-D5019-05-03.PrjPcb, L-D5019-05-03.SchDoc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]
2021-12-31 updated schematics template
    [L-D5019-01-04.PrjPcb, L-D5019-01-04.SchDoc, L-D5019-01-05.PrjPcb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]
2022-04-23 - added L-D5019-08 which is a simpler version to be used with breadboards
    [L-D5019-01-04.PcbDoc, L-D5019-01-04.PrjPcb, L-D5019-01-04.SchDoc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]
2022-05-08 - added D5019-08-02
    [L-D5019-08.PcbDoc, L-D5019-08.PrjPcb, L-D5019-08.SchDoc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]
2023-08-20 - added BOM and Pick&Place files for PCB assembly at JLCPCB
    [L_D5019-08_BOM.xlsx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]
2024-02-23 - idea for improving the switching_regulator
2024-02-23 - alternative switching_regulator layout
2024-07-08 - swapped VCC and GND positions on the pin headers, now there is 1 VCC pin and 4 GND pins
    - loop-optimized the switching regulator
    [L-D5019-08-01.PcbDoc, L-D5019-08-01.SchDoc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]
